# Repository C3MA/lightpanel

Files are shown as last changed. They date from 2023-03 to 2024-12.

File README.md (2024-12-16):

# moved to https://www.ccc-mannheim.de/wiki/Lightpanel

# lightpanel v1.0

###Import application note
Do not chain Multiple boards while powering only via USB!

The Voltage converters will reverse feed the second board, and in the process kill most of the LED's on the first board!

ESP32C3 notice:
If flashing while connected to the board, the ESP might damage it's

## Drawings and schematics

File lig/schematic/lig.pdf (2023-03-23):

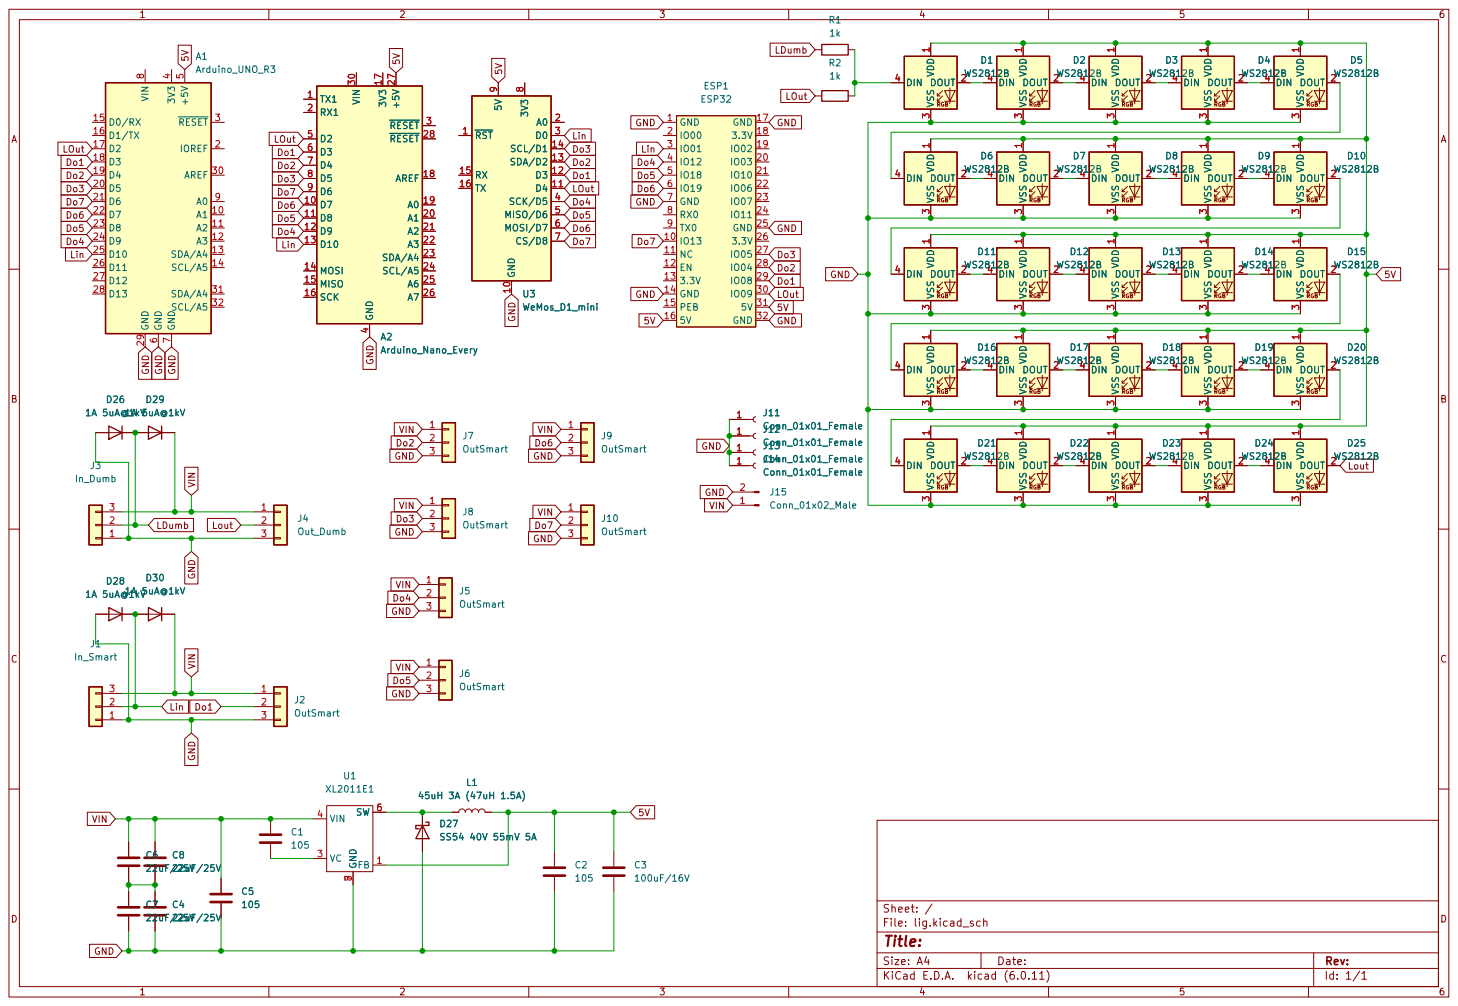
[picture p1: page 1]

Id: 1/1 Title: File: lig.kicad_sch Sheet: /

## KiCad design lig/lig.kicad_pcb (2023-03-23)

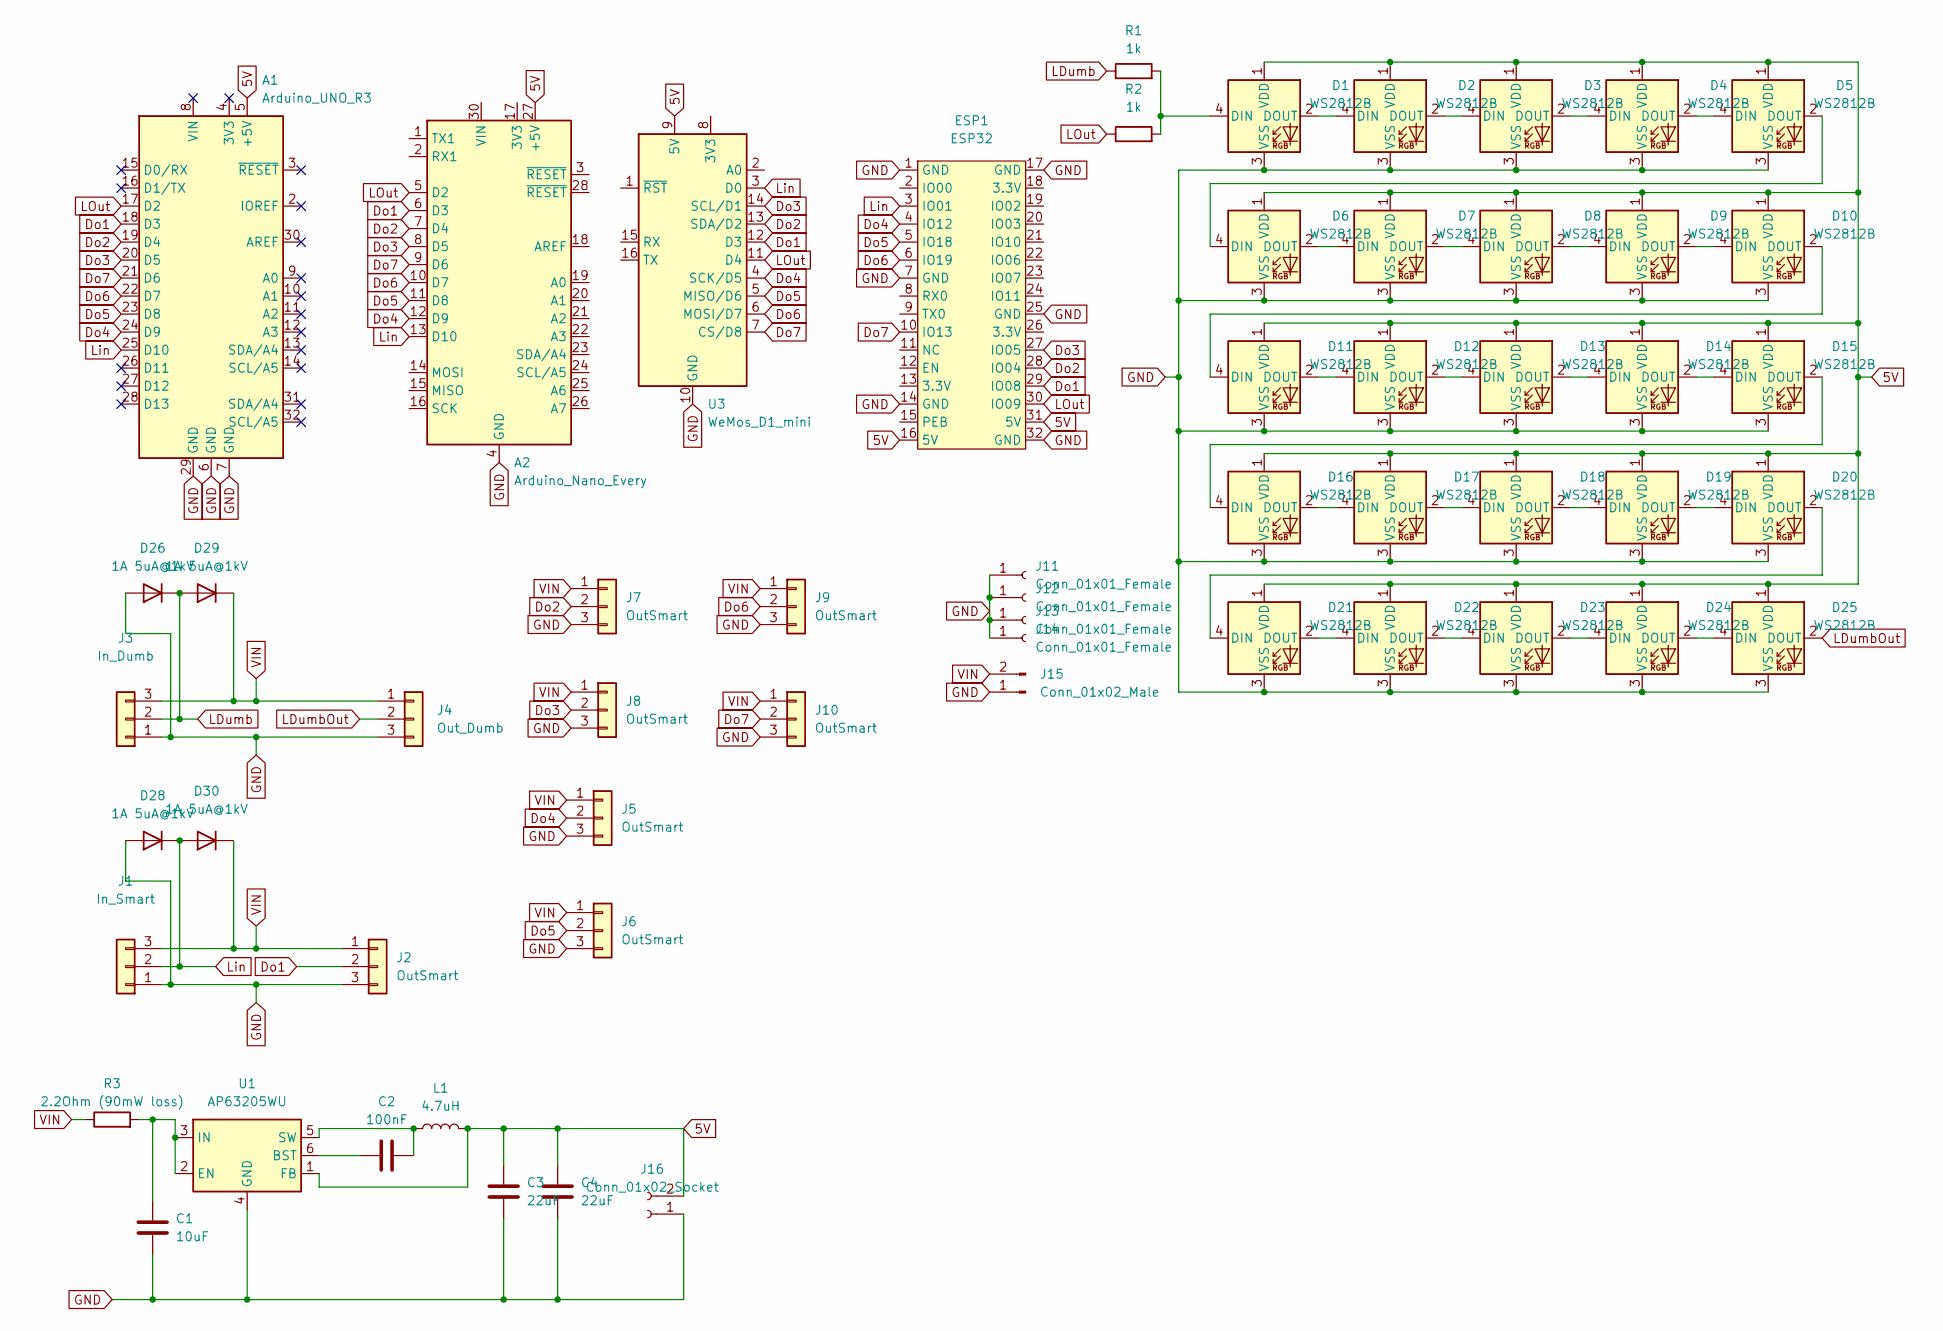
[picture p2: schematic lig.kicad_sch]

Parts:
A1: Arduino_UNO_R3
A2: Arduino_Nano_Every; Arduino_Nano
C1: 10uF; C_1206_3216Metric; LCSC C13585
C2: 100nF; C_0603_1608Metric; LCSC C14663
C3, C4: 22uF; C_1206_3216Metric; LCSC C15008
D1, D2, D3, D4, D5, D6, D7, D8, D9, D10, D11, D12, D13, D14, D15, D16, D17, D18, D19, D20, D21, D22, D23, D24, D25: WS2812B; LED_WS2812B_PLCC4_5.0x5.0mm_P3.2mm; LCSC C2843785
D26, D28, D29, D30: 1A 5uA@1kV; D_SOD-123F; LCSC C64898
ESP1: ESP32; Luatos
J1: In_Smart; JST_PH_B3B-PH-SM4-TB_1x03-1MP_P2.00mm_Vertical
J2, J5, J6, J7, J8, J9, J10: OutSmart; JST_PH_B3B-PH-SM4-TB_1x03-1MP_P2.00mm_Vertical
J3: In_Dumb; JST_PH_B3B-PH-SM4-TB_1x03-1MP_P2.00mm_Vertical; LCSC C2688785
J4: Out_Dumb; JST_PH_B3B-PH-SM4-TB_1x03-1MP_P2.00mm_Vertical; LCSC C2688785
J11, J12, J13, J14: Conn_01x01_Female; Solder_Screw_Mount
J15: Conn_01x02_Male; AMASS_XT60-M_1x02_P7.20mm_Vertical
J16: Conn_01x02_Socket; PinHeader_1x02_P2.54mm_Vertical
L1: 4.7uH; L_1210_3225Metric; LCSC C90319
R1, R2: 1k; R_0603_1608Metric; LCSC C21190
R3: 2.2Ohm (90mW loss); R_0805_2012Metric; LCSC C17513
U1: AP63205WU; TSOT-23-6; LCSC C2071056
U3: WeMos_D1_mini; WEMOS_D1_mini_light

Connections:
5V: A1.5 (+5V), A2.27 (+5V), C3.1, C4.1, D1.1 (VDD), D2.1 (VDD), D3.1 (VDD), D4.1 (VDD), D5.1 (VDD), D6.1 (VDD), D7.1 (VDD), D8.1 (VDD), D9.1 (VDD), D10.1 (VDD), D11.1 (VDD), D12.1 (VDD), D13.1 (VDD), D14.1 (VDD), D15.1 (VDD), D16.1 (VDD), D17.1 (VDD), D18.1 (VDD), D19.1 (VDD), D20.1 (VDD), D21.1 (VDD), D22.1 (VDD), D23.1 (VDD), D24.1 (VDD), D25.1 (VDD), ESP1.16 (5V), ESP1.31 (5V), J16.2, L1.2, U1.1 (FB), U3.9 (5V)
Do1: A1.18 (D3), A2.6 (D3), ESP1.29 (IO08), J2.2, U3.12 (D3)
Do2: A1.19 (D4), A2.7 (D4), ESP1.28 (IO04), J7.2, U3.13 (SDA/D2)
Do3: A1.20 (D5), A2.8 (D5), ESP1.27 (IO05), J8.2, U3.14 (SCL/D1)
Do4: A1.24 (D9), A2.12 (D9), ESP1.4 (IO12), J5.2, U3.4 (SCK/D5)
Do5: A1.23 (D8), A2.11 (D8), ESP1.5 (IO18), J6.2, U3.5 (MISO/D6)
Do6: A1.22 (D7), A2.10 (D7), ESP1.6 (IO19), J9.2, U3.6 (MOSI/D7)
Do7: A1.21 (D6), A2.9 (D6), ESP1.10 (IO13), J10.2, U3.7 (CS/D8)
GND: A1.6 (GND), A1.7 (GND), A1.29 (GND), A2.4 (GND), A2.29 (GND), C1.2, C3.2, C4.2, D1.3 (VSS), D2.3 (VSS), D3.3 (VSS), D4.3 (VSS), D5.3 (VSS), D6.3 (VSS), D7.3 (VSS), D8.3 (VSS), D9.3 (VSS), D10.3 (VSS), D11.3 (VSS), D12.3 (VSS), D13.3 (VSS), D14.3 (VSS), D15.3 (VSS), D16.3 (VSS), D17.3 (VSS), D18.3 (VSS), D19.3 (VSS), D20.3 (VSS), D21.3 (VSS), D22.3 (VSS), D23.3 (VSS), D24.3 (VSS), D25.3 (VSS), D26.2 (A), D28.2 (A), ESP1.1 (GND), ESP1.7 (GND), ESP1.14 (GND), ESP1.17 (GND), ESP1.25 (GND), ESP1.32 (GND), J1.1, J2.3, J3.1, J4.3, J5.3, J6.3, J7.3, J8.3, J9.3, J10.3, J11.1, J12.1, J13.1, J14.1, J15.1, J16.1, U1.4 (GND), U3.10 (GND)
LDumb: D26.1 (K), D29.2 (A), J3.2, R1.1
LDumbOut: D25.2 (DOUT), J4.2
LOut: A1.17 (D2), A2.5 (D2), ESP1.30 (IO09), R2.1, U3.11 (D4)
Lin: A1.25 (D10), A2.13 (D10), D28.1 (K), D30.2 (A), ESP1.3 (IO01), J1.2, U3.3 (D0)
unnamed: D1.4 (DIN), R1.2, R2.2
unnamed: D1.2 (DOUT), D2.4 (DIN)
unnamed: D2.2 (DOUT), D3.4 (DIN)
unnamed: D3.2 (DOUT), D4.4 (DIN)
unnamed: D4.2 (DOUT), D5.4 (DIN)
unnamed: D5.2 (DOUT), D6.4 (DIN)
unnamed: D6.2 (DOUT), D7.4 (DIN)
unnamed: D7.2 (DOUT), D8.4 (DIN)
unnamed: D8.2 (DOUT), D9.4 (DIN)
unnamed: D9.2 (DOUT), D10.4 (DIN)
unnamed: D10.2 (DOUT), D11.4 (DIN)
unnamed: D11.2 (DOUT), D12.4 (DIN)
unnamed: D12.2 (DOUT), D13.4 (DIN)
unnamed: D13.2 (DOUT), D14.4 (DIN)
unnamed: D14.2 (DOUT), D15.4 (DIN)
unnamed: D15.2 (DOUT), D16.4 (DIN)
unnamed: D16.2 (DOUT), D17.4 (DIN)
unnamed: D17.2 (DOUT), D18.4 (DIN)
unnamed: D18.2 (DOUT), D19.4 (DIN)
unnamed: D19.2 (DOUT), D20.4 (DIN)
unnamed: D20.2 (DOUT), D21.4 (DIN)
unnamed: D21.2 (DOUT), D22.4 (DIN)
unnamed: D22.2 (DOUT), D23.4 (DIN)
unnamed: D23.2 (DOUT), D24.4 (DIN)
unnamed: D24.2 (DOUT), D25.4 (DIN)
unnamed: C2.1, U1.6 (BST)
unnamed: C1.1, R3.2, U1.2 (EN), U1.3 (IN)
unnamed: C2.2, L1.1, U1.5 (SW)
VIN: D29.1 (K), D30.1 (K), J1.3, J2.1, J3.3, J4.1, J5.1, J6.1, J7.1, J8.1, J9.1, J10.1, J15.2, R3.1

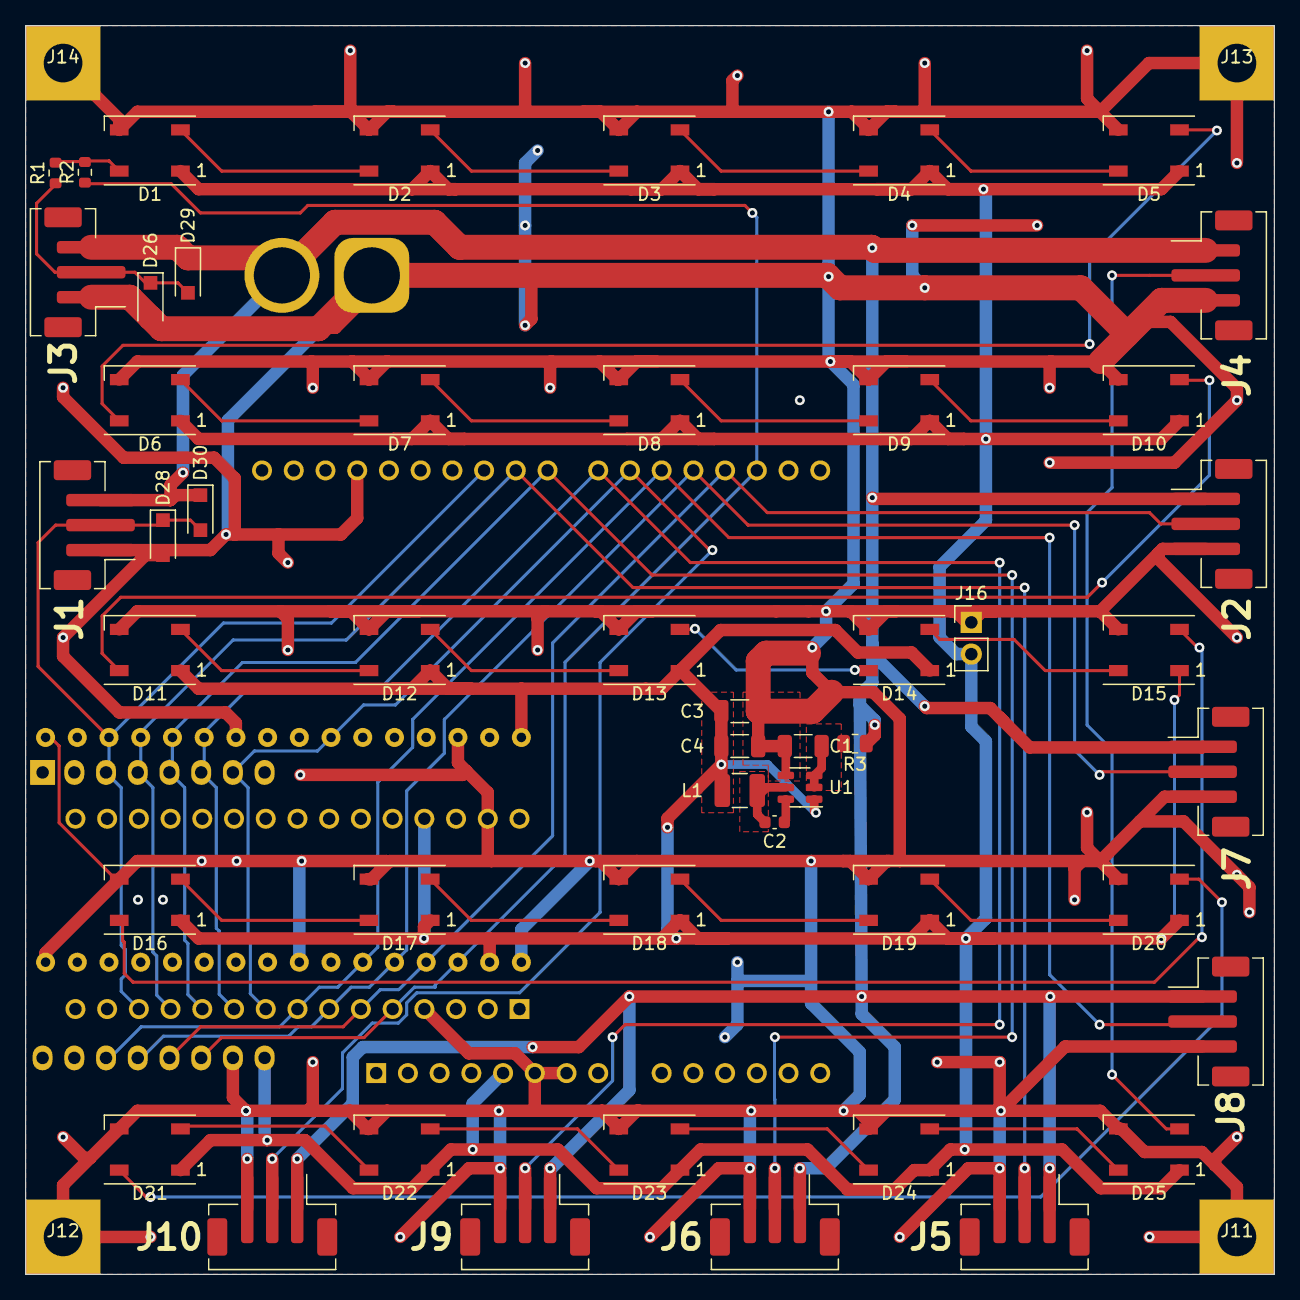
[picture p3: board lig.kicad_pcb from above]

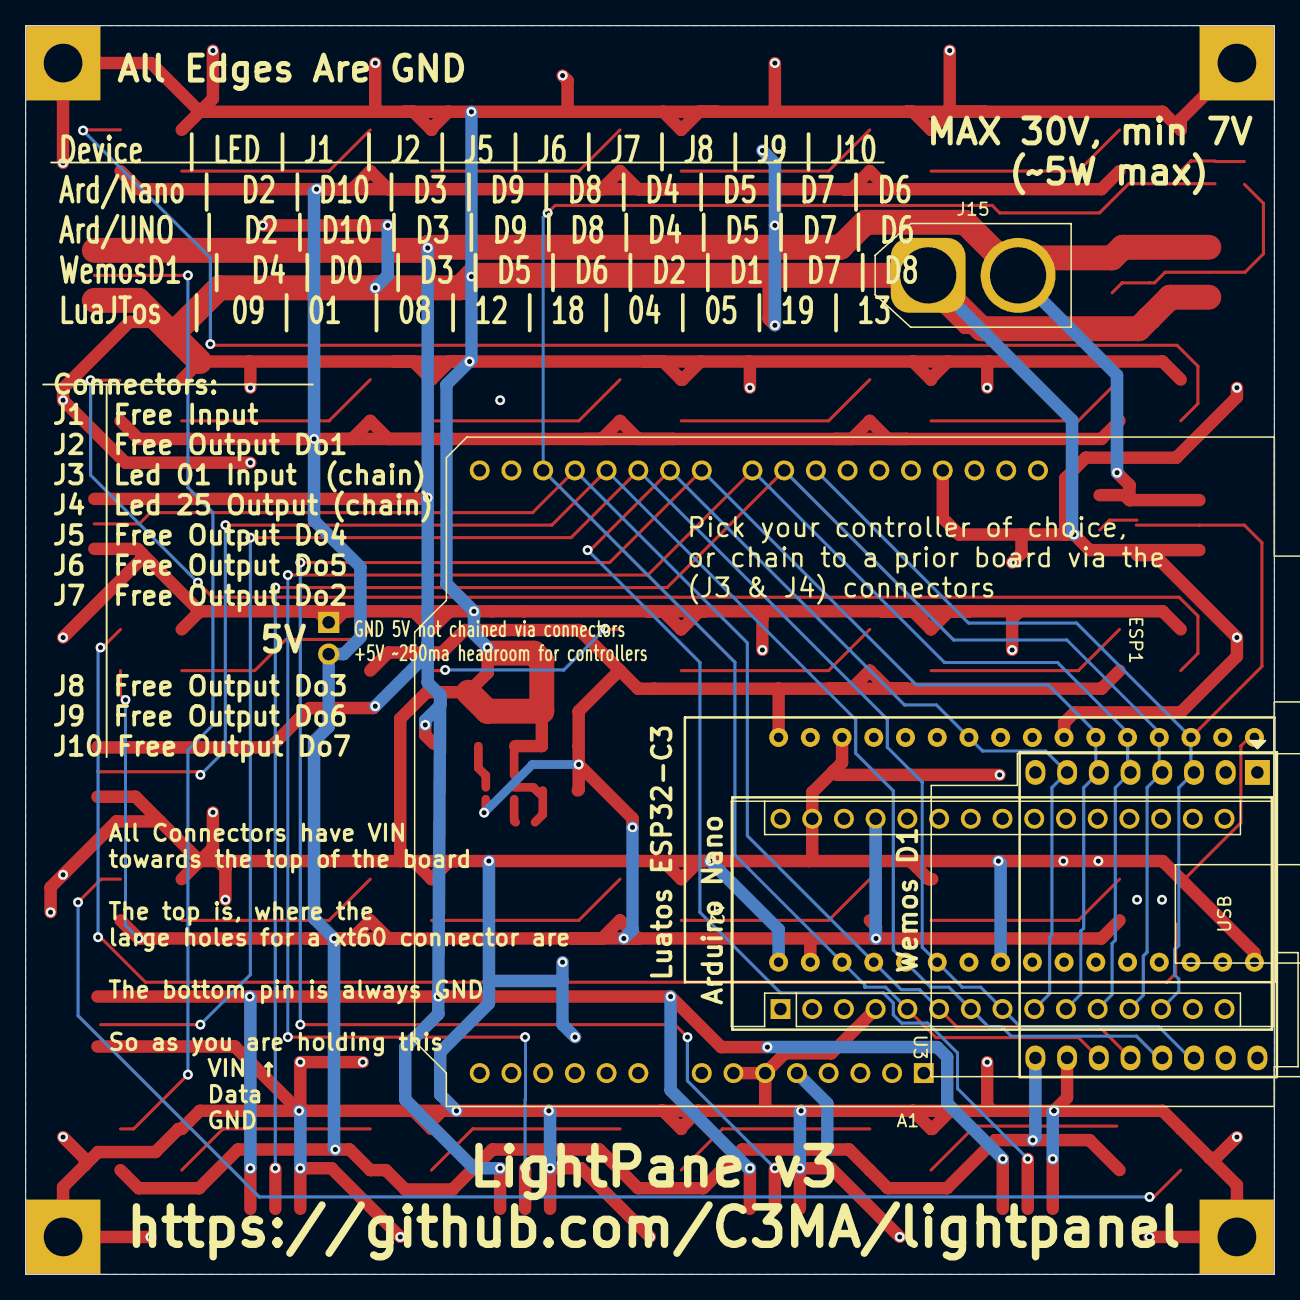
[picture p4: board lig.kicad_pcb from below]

Board: 2 copper layers, 100.0 x 100.0 mm, 58 parts (5 on the bottom side), 42 nets.

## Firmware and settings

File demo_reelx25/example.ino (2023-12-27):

/// @file    DemoReel100.ino
/// @brief   FastLED "100 lines of code" demo reel, showing off some effects
/// @example DemoReel100.ino

#include <FastLED.h>

FASTLED_USING_NAMESPACE

// FastLED "100-lines-of-code" demo reel, showing just a few 
// of the kinds of animation patterns you can quickly and easily 
// compose using FastLED.  
//
// This example also shows one easy way to define multiple 
// animations patterns and have them automatically rotate.
//
// -Mark Kriegsman, December 2014


#define DATA_PIN    2
//#define CLK_PIN   4
#define LED_TYPE    WS2811
#define COLOR_ORDER GRB
#define NUM_LEDS    26
CRGB leds[NUM_LEDS];
CRGB leds25[NUM_LEDS*25];

#define BRIGHTNESS          255
#define FRAMES_PER_SECOND  60

void setup() {
  delay(3000); // 3 second delay for recovery
  
  // tell FastLED about the LED strip configuration
  FastLED.addLeds<LED_TYPE,DATA_PIN,COLOR_ORDER>(leds25, NUM_LEDS*25).setCorrection(TypicalLEDStrip);
  //FastLED.addLeds<LED_TYPE,DATA_PIN,CLK_PIN,COLOR_ORDER>(leds, NUM_LEDS).setCorrection(TypicalLEDStrip);

  // set master brightness control
  FastLED.setBrightness(BRIGHTNESS);
}


// List of patterns to cycle through.  Each is defined as a separate function below.
typedef void (*SimplePatternList[])();
SimplePatternList gPatterns = { rainbow, rainbowWithGlitter, confetti, sinelon, juggle, bpm };

uint8_t gCurrentPatternNumber = 0; // Index number of which pattern is current
uint8_t gHue = 0; // rotating "base color" used by many of the patterns
  
void loop()
{
  // Call the current pattern function once, updating the 'leds' array
  gPatterns[gCurrentPatternNumber]();

  // send the 'leds' array out to the actual LED strip
  for(int i = 0;i<NUM_LEDS;i++){
    for(int j= 0;j<25;j++){
      leds25[i*25+j]=leds[i];
    }
  }
  FastLED.show();  
  // insert a delay to keep the framerate modest
  FastLED.delay(1000/FRAMES_PER_SECOND); 

  // do some periodic updates
  EVERY_N_MILLISECONDS( 20 ) { gHue++; } // slowly cycle the "base color" through the rainbow
  EVERY_N_SECONDS( 10 ) { nextPattern(); } // change patterns periodically
}

#define ARRAY_SIZE(A) (sizeof(A) / sizeof((A)[0]))

void nextPattern()
{
  // add one to the current pattern number, and wrap around at the end
  gCurrentPatternNumber = (gCurrentPatternNumber + 1) % ARRAY_SIZE( gPatterns);
}

void rainbow() 
{
  // FastLED's built-in rainbow generator
  fill_rainbow( leds, NUM_LEDS, gHue, 7);
}

void rainbowWithGlitter() 
{
  // built-in FastLED rainbow, plus some random sparkly glitter
  rainbow();
  addGlitter(80);
}

void addGlitter( fract8 chanceOfGlitter) 
{
  if( random8() < chanceOfGlitter) {
    leds[ random16(NUM_LEDS) ] += CRGB::White;
  }
}

void confetti() 
{
  // random colored speckles that blink in and fade smoothly
  fadeToBlackBy( leds, NUM_LEDS, 10);
  int pos = random16(NUM_LEDS);
  leds[pos] += CHSV( gHue + random8(64), 200, 255);
}

void sinelon()
{
  // a colored dot sweeping back and forth, with fading trails
  fadeToBlackBy( leds, NUM_LEDS, 20);
  int pos = beatsin16( 13, 0, NUM_LEDS-1 );
  leds[pos] += CHSV( gHue, 255, 192);
}

void bpm()
{
  // colored stripes pulsing at a defined Beats-Per-Minute (BPM)
  uint8_t BeatsPerMinute = 62;
  CRGBPalette16 palette = PartyColors_p;
  uint8_t beat = beatsin8( BeatsPerMinute, 64, 255);
  for( int i = 0; i < NUM_LEDS; i++) { //9948
    leds[i] = ColorFromPalette(palette, gHue+(i*2), beat-gHue+(i*10));
  }
}

void juggle() {
  // eight colored dots, weaving in and out of sync with each other
  fadeToBlackBy( leds, NUM_LEDS, 20);
  uint8_t dothue = 0;
  for( int i = 0; i < 8; i++) {
    leds[beatsin16( i+7, 0, NUM_LEDS-1 )] |= CHSV(dothue, 200, 255);
    dothue += 32;
  }
}

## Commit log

2023-03-23 initial data
    [lig.kicad_pcb, lig.kicad_sch]
2023-05-28 added footprint
    [lig.kicad_sch]
2023-12-27 v2 changes
    [lig.kicad_sch]
2024-02-22 v2 diodes and simplification
    [lig.kicad_sch]
